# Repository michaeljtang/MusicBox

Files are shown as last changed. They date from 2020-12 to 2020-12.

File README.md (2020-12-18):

# MusicBox

Electronic music box project powered by a PocketBeagle. Full project description can be found on Hackster: https://www.hackster.io/michael-tang/programmable-music-box-1288ab

The mechanical instructions for building this project can be found in the Hackster page above. This repo contains two main folders:

### Code
This folder contains all code needed to operate the music box, as well as instructions on how to run on startup.

### PCB
This folder contains the schematic, layout, library, and more for manufacturing the PCB version of the prototype presented in the Hackster page above.

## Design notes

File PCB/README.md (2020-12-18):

# Music Box PCB

This folder includes all files necessary to manufacture a PCB for my electronic music box project. More specifically, the PCB created is intended to host all components (or connectors to components, if they are too big) necessary for the music box to run. 

In addition to a Bill-of-Materials and and PCB Schematic, this directory contains the following folders:

### /EAGLE
This folder contains the Eagle files of my PCB, and include schematic, board, as well as a library with all parts used.

### /MFG
This folder contains all the Gerber manufacturing files needed to actually manufacture my PCB

### /docs
This folder contains images of the top and bottom views of my PCB (taken from Gerber files).

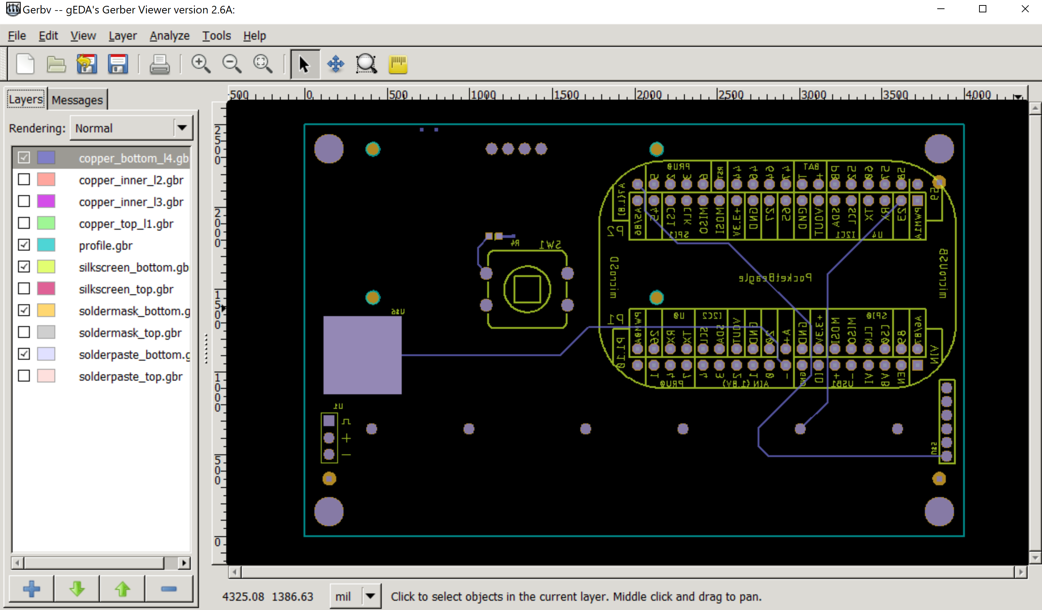
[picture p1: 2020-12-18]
PCB/docs/bottom_layer.png

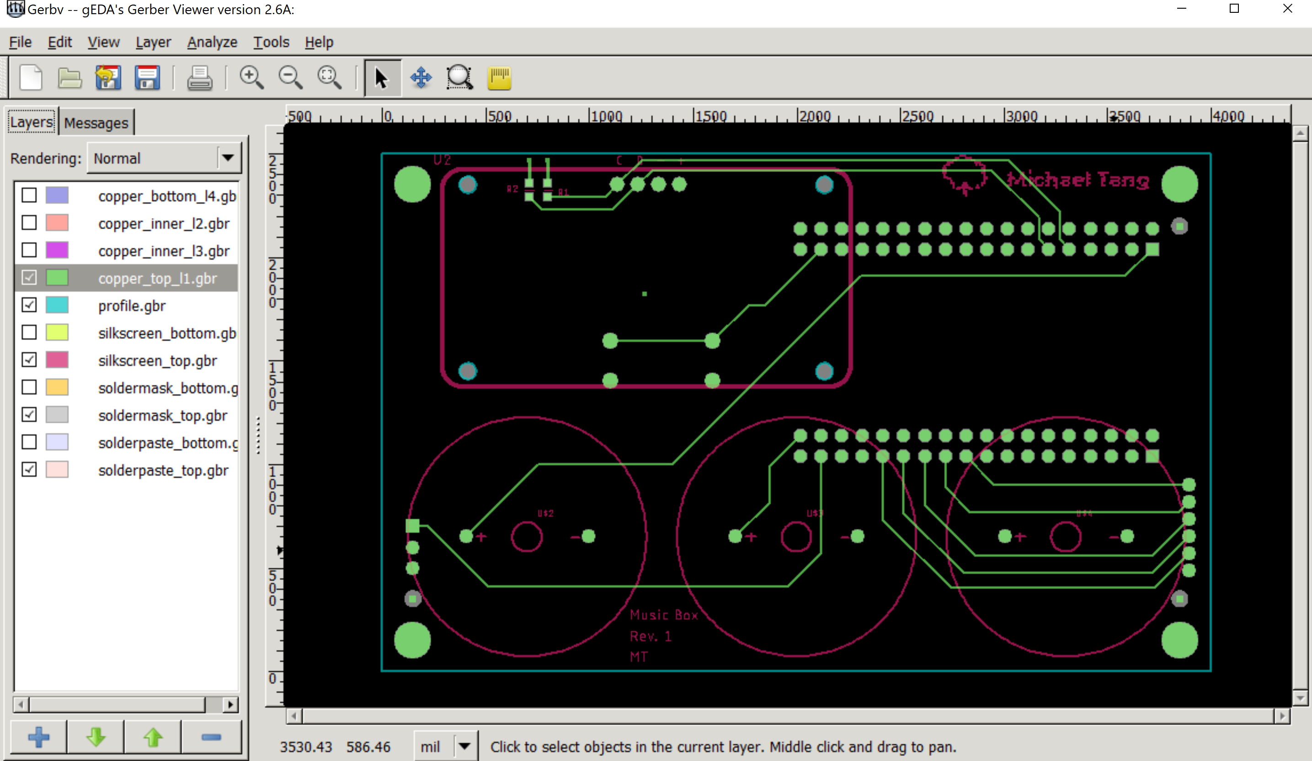
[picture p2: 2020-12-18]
PCB/docs/top_layer.png

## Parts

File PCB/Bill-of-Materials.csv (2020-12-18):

Qty | Manufacturer/MPN | Value | Device | Package | Parts/Designator | Description
1 | Adafruit HT16K33 | 0.56_HEX_BACKPACK | 0.56_HEX_BACKPACK | 0.56_HEX_BACKPACK | U2 | 0.56" LED HEX Backback - Adafruit HT16K33 -
3 | MF-RES-0603-1K | 1k | R_R0603 | R0603 | R1, R2, R4 | RESISTOR, American symbol
1 | N/A | COPPER_PLATE | COPPER_PLATE | COPPER_PLATE | U$6 | Copper plate to serve as a grounded surface
6 | N/A | FIDUCIAL | FIDUCIAL | FIDUCIAL_40MIL | FUD1, FUD2, FUD3, FUD4, FUD5, FUD6 | Fiducials to aid PCB manufacturing
1 | N/A | HEADER_PINS | HEADER_PINS | HEADER_PINS | U$5 | Standard Header Pins to act as floating analog inputs
4 | N/A | MOUNTING_HOLE | MOUNTING_HOLE | MOUNTING_HOLE | MGT1, MGT2, MGT3, MGT4 | Chassis Mounting Hole w/GND connection ability
1 | BeagleBoard | POCKETBEAGLE | POCKETBEAGLE | POCKETBEAGLE | U$1 | Microcontroller running 1GHz ARM Cortex-A8
1 | Gikfun LYSB01E38OS7K-ELECTRNCS | PUSH_BUTTON | PUSH_BUTTON | BUTTON_12.5MM | SW1 | Standard Push Button
1 | Sparkfun ROB10189 | SERVO_ROB10189 | SERVO_ROB10190 | SERVO-X1 | U1 | Continuous Rotation Servo (Micro-Size)
3 | Adafruit P1898 | SPEAKER_P1898 | SPEAKER_P1899 | SPEAKER | U$2, U$3, U$4 | PCB Mount Mini Speaker

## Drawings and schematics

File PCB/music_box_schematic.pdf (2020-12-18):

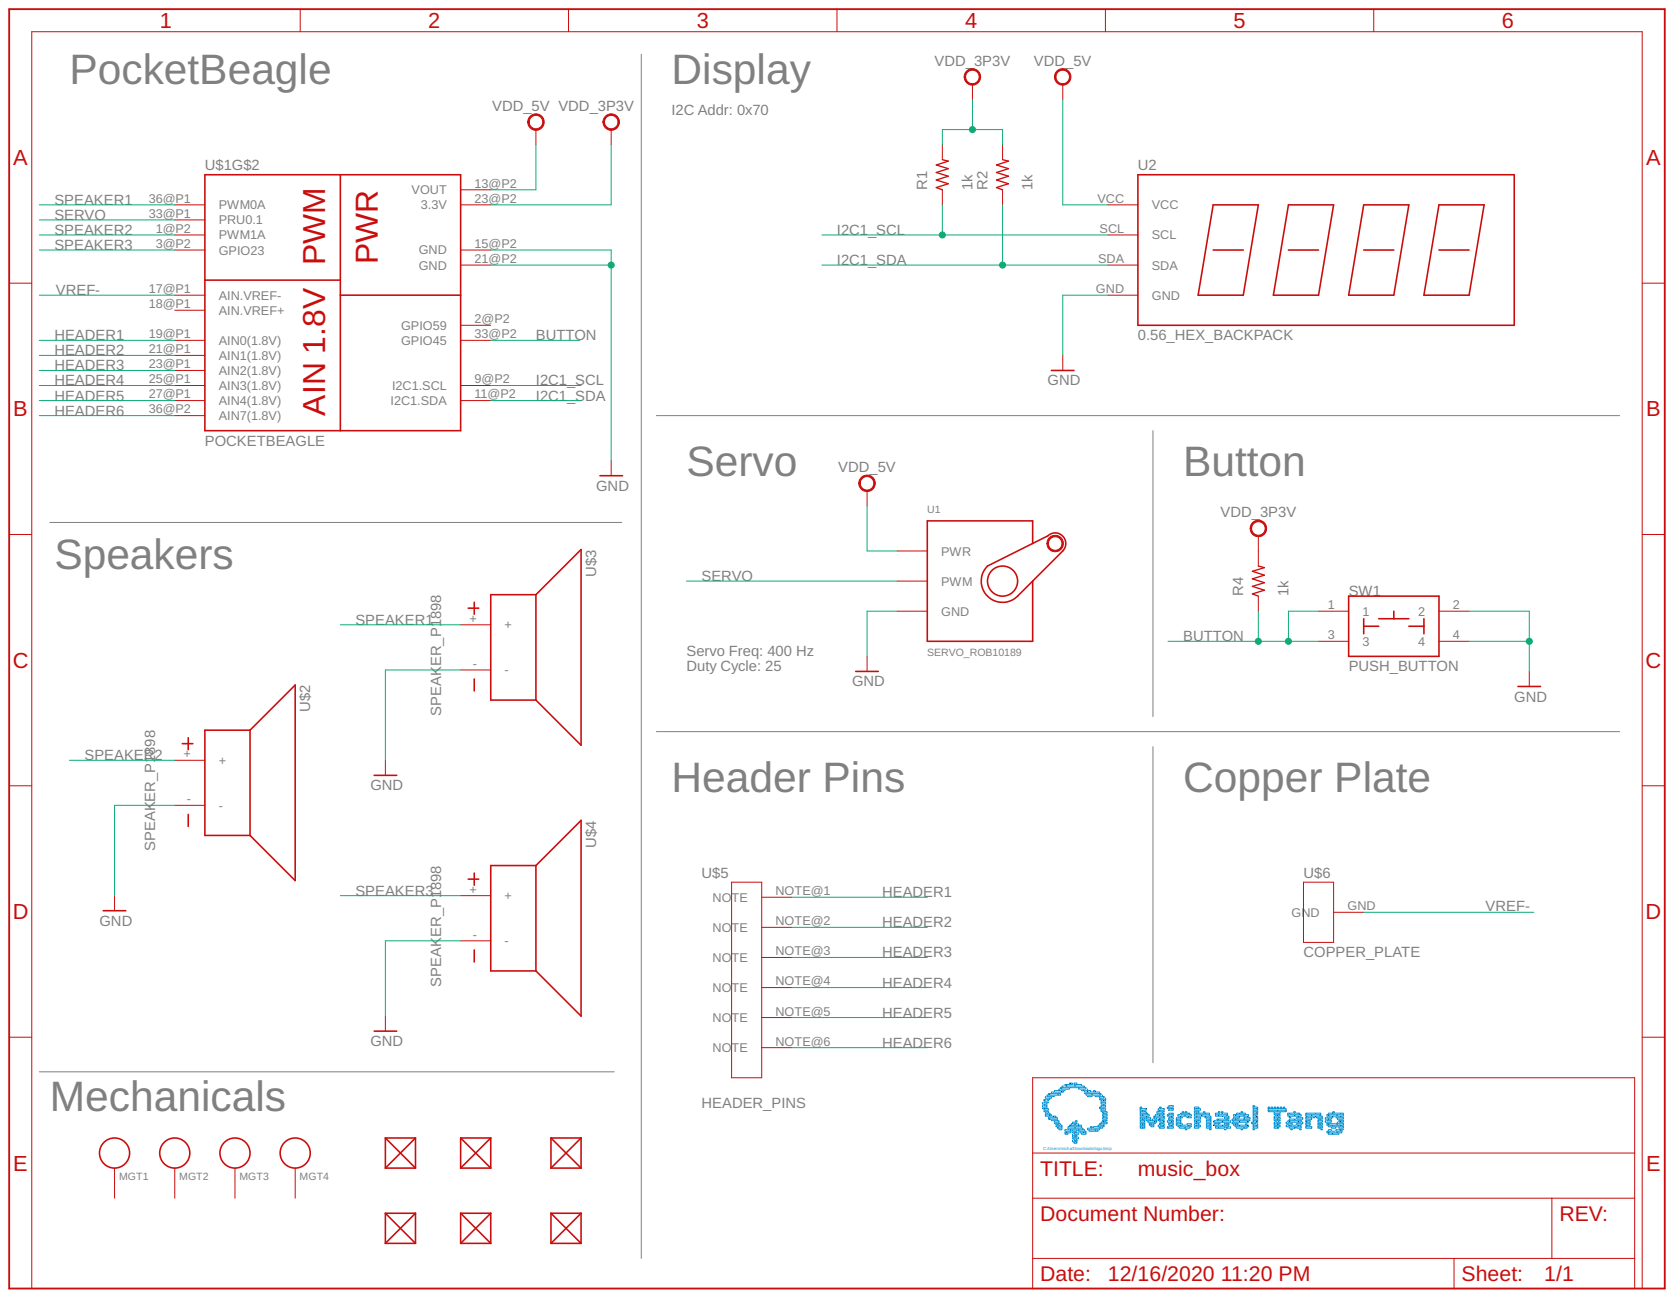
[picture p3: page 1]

HEADER1 | GPIO59 I2C1.SCL I2C1.SDA

HEADER2 | | 9@P2 I2C1_SCL

Servo Freq: 400 Hz Duty Cycle: 25

C:/Users/micha/Downloads/logo.bmp
TITLE:

Document Number: | REV:

Date: 12/16/2020 11:20 PM | Sheet: 1/1

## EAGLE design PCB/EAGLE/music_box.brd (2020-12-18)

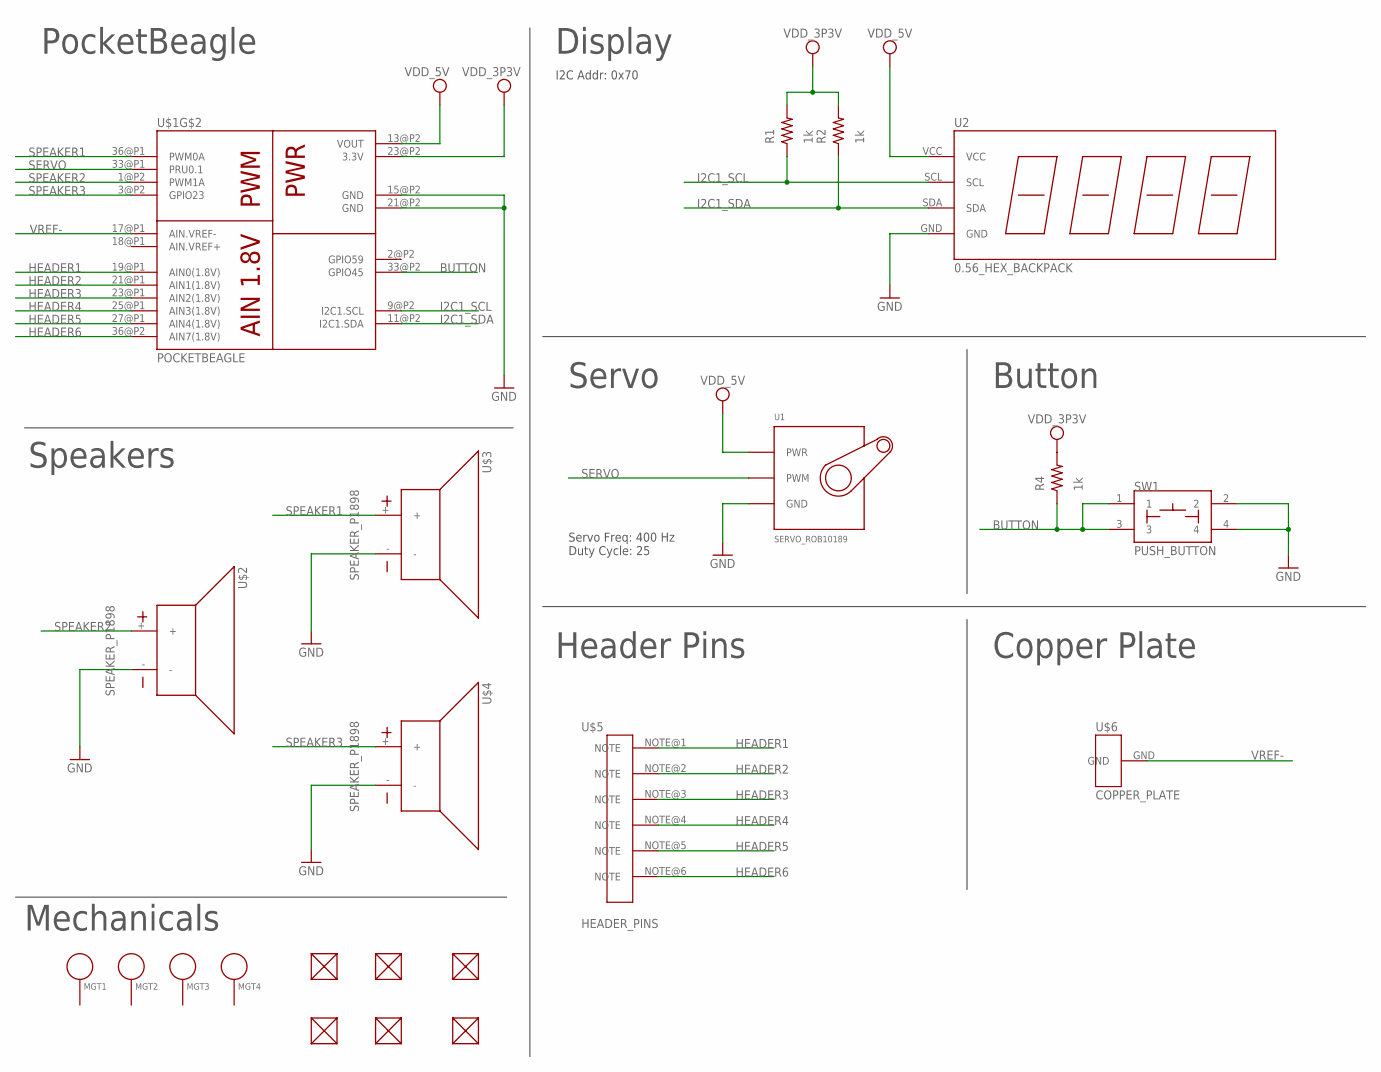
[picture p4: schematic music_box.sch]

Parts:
FUD1, FUD2, FUD3, FUD4, FUD5, FUD6: FIDUCIAL; FIDUCIAL_40MIL
MGT1, MGT2, MGT3, MGT4: MOUNTING_HOLE
R1, R2, R4: 1k; R0603
SW1: PUSH_BUTTON; BUTTON_12.5MM
U1: SERVO_ROB10189; SERVO-X1
U2: 0.56_HEX_BACKPACK
U$1: POCKETBEAGLE
U$2, U$3, U$4: SPEAKER_P1898; SPEAKER
U$5: HEADER_PINS
U$6: COPPER_PLATE

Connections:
BUTTON: R4.1, SW1.1, SW1.3, U$1.33@P2 (GPIO45)
GND: SW1.2, SW1.4, U1.GND, U2.GND, U$1.15@P2 (GND), U$1.21@P2 (GND), U$2.-, U$3.-, U$4.-
HEADER1: U$1.19@P1 (AIN0(1.8V)), U$5.NOTE@1
HEADER2: U$1.21@P1 (AIN1(1.8V)), U$5.NOTE@2
HEADER3: U$1.23@P1 (AIN2(1.8V)), U$5.NOTE@3
HEADER4: U$1.25@P1 (AIN3(1.8V)), U$5.NOTE@4
HEADER5: U$1.27@P1 (AIN4(1.8V)), U$5.NOTE@5
HEADER6: U$1.36@P2 (AIN7(1.8V)), U$5.NOTE@6
I2C1_SCL: R1.1, U2.SCL, U$1.9@P2 (I2C1.SCL)
I2C1_SDA: R2.1, U2.SDA, U$1.11@P2 (I2C1.SDA)
SERVO: U1.SIG (PWM), U$1.33@P1 (PRU0.1)
SPEAKER1: U$1.36@P1 (PWM0A), U$3.+
SPEAKER2: U$1.1@P2 (PWM1A), U$2.+
SPEAKER3: U$1.3@P2 (GPIO23), U$4.+
VDD_3P3V: R1.2, R2.2, R4.2, U$1.23@P2 (3.3V)
VDD_5V: U1.PWR, U2.VCC, U$1.13@P2 (VOUT)
VREF-: U$1.17@P1 (AIN.VREF-), U$6.GND

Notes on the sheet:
PocketBeagle
Display
Servo
Button
Header Pins
Copper Plate
Speakers
I2C Addr: 0x70
Servo Freq: 400 Hz Duty Cycle: 25
Mechanicals

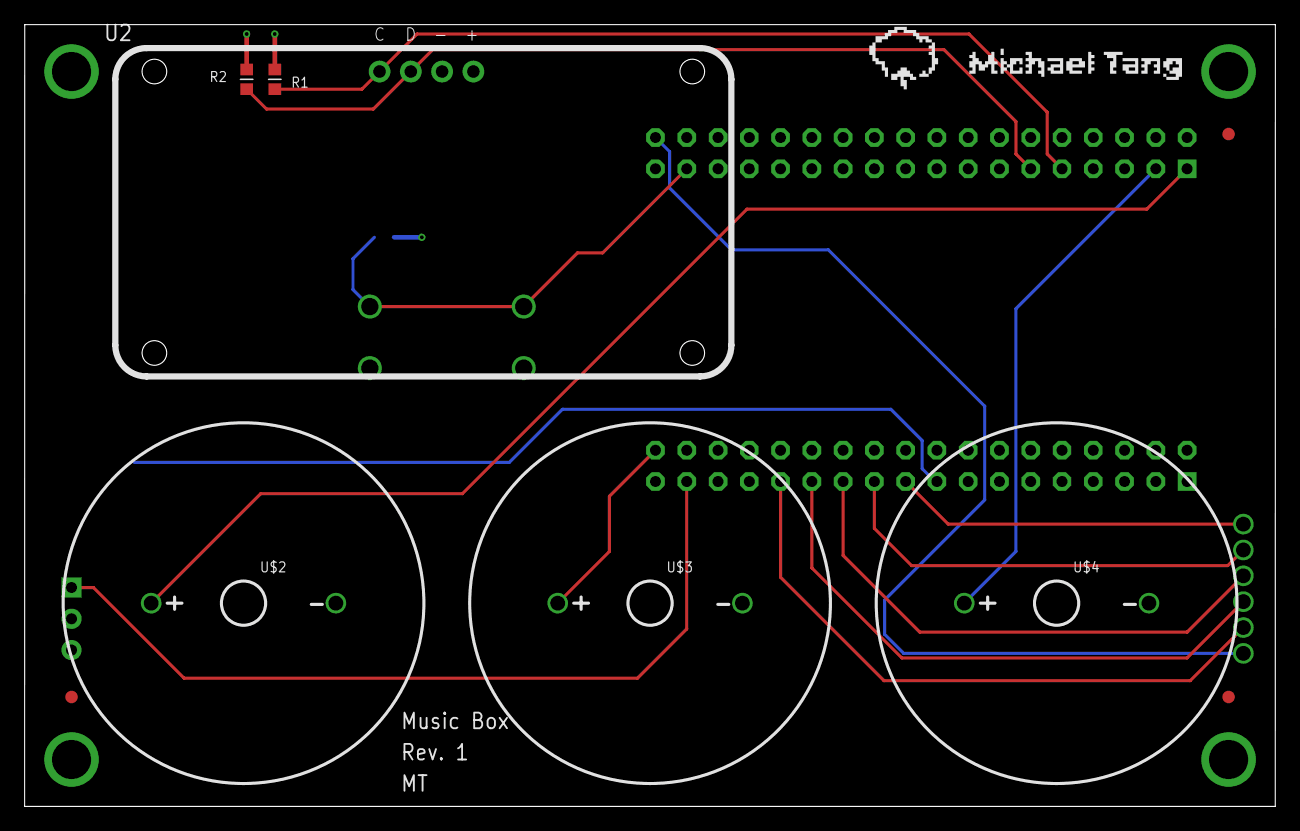
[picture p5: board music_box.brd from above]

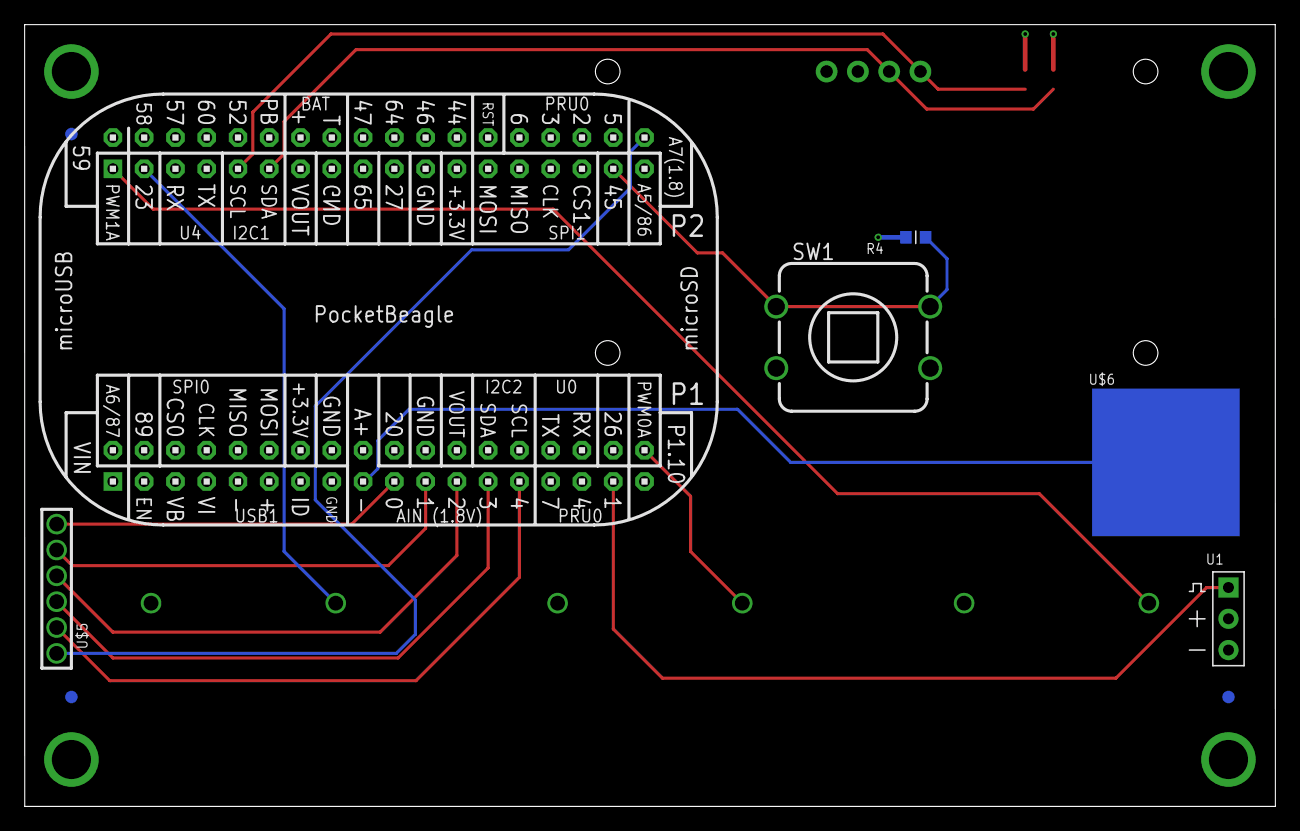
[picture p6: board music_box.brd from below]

Board: 4 copper layers, 101.6 x 63.5 mm, 22 parts (9 on the bottom side), 17 nets.

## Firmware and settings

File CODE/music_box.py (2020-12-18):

"""
--------------------------------------------------------------------------
Music Box
--------------------------------------------------------------------------
License:   
Copyright 2020 Michael Tang

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
1. Redistributions of source code must retain the above copyright notice, this 
list of conditions and the following disclaimer.

2. Redistributions in binary form must reproduce the above copyright notice, 
this list of conditions and the following disclaimer in the documentation 
and/or other materials provided with the distribution.

3. Neither the name of the copyright holder nor the names of its contributors 
may be used to endorse or promote products derived from this software without 
specific prior written permission.

THIS SOFTWARE IS PROVIDED BY THE COPYRIGHT HOLDERS AND CONTRIBUTORS "AS IS" 
AND ANY EXPRESS OR IMPLIED WARRANTIES, INCLUDING, BUT NOT LIMITED TO, THE 
IMPLIED WARRANTIES OF MERCHANTABILITY AND FITNESS FOR A PARTICULAR PURPOSE ARE 
DISCLAIMED. IN NO EVENT SHALL THE COPYRIGHT HOLDER OR CONTRIBUTORS BE LIABLE 
FOR ANY DIRECT, INDIRECT, INCIDENTAL, SPECIAL, EXEMPLARY, OR CONSEQUENTIAL 
DAMAGES (INCLUDING, BUT NOT LIMITED TO, PROCUREMENT OF SUBSTITUTE GOODS OR 
SERVICES; LOSS OF USE, DATA, OR PROFITS; OR BUSINESS INTERRUPTION) HOWEVER 
CAUSED AND ON ANY THEORY OF LIABILITY, WHETHER IN CONTRACT, STRICT LIABILITY, 
OR TORT (INCLUDING NEGLIGENCE OR OTHERWISE) ARISING IN ANY WAY OUT OF THE USE 
OF THIS SOFTWARE, EVEN IF ADVISED OF THE POSSIBILITY OF SUCH DAMAGE.
--------------------------------------------------------------------------
Software for running a programmable music box.

Main Components used:
  - HT16K33 Display
  - 1 push button
  - 3 speakers
  - 1 Micro-size continuous rotation servo
  - Copper plate

Uses:
  - HT16K33 display library developed by Erik Welsh
  - motor.py (in folder) for running thread for continuous rotation servo
  - speaker.py (in folder) for running thread for speaker

"""
from speaker import *
from motor import *
import Adafruit_BBIO.GPIO as GPIO
import Adafruit_BBIO.ADC as ADC
import threading

import ht16k33 as HT16K33

# ------------------------------------------------------------------------
# Constants
# ------------------------------------------------------------------------
# threshold sets what voltages our pins need to hit for a sound to be played
THRESHOLD = 500

# ------------------------------------------------------------------------
# Global variables
# ------------------------------------------------------------------------
# determines whether our music box is on or off; is controlled by the Button thread, and affects the MusicBox class
music_box_on = False

class MusicBox():
    # pins corresponding to each speaker, and a list for storing each speaker's threads
    speaker_0 = None
    speaker_1 = None
    speaker_2 = None
    speaker_threads = []
    
    # dict to store pins corresponding to each note
    note_pins = {}
    
    # object representing 7-segment display
    display = None
    
    # object representing motor
    motor = None
    motor_thread = None
    
    def __init__(self, speaker_0="P1_36", speaker_1="P2_3", speaker_2="P2_1", C="P1_27", D="P1_19", E="P1_21", F="P1_23", G="P1_25", A="P2_35", B="P2_36", i2c_bus=1, i2c_address=0x70, motor="P1_33"):
        """
        Intializes variables to appropriate pins
        """
        # initialize speaker pins
        self.speaker_0 = speaker_0
        self.speaker_1 = speaker_1
        self.speaker_2 = speaker_2

        # initialize note pins
        #self.note_pins['A'] = A
        self.note_pins['B'] = B
        self.note_pins['C'] = C
        self.note_pins['D'] = D
        self.note_pins['E'] = E
        self.note_pins['F'] = F
        self.note_pins['G'] = G
        
        # initialize 7-segment display
        self.display = HT16K33.HT16K33(i2c_bus, i2c_address)
        
        # Initialize motor pin
        self.motor = motor
        
        # setup all of the pins
        self._setup()
    
    def _setup(self):
        """
        Sets up device for initial use
        """
        # Initialize Display
        self.set_display_off()
        
        # Initialize Analog Inputs
        ADC.setup()
        
        # Initialize Motor
        self.motor_thread = RunMotor(self.motor)       
        self.motor_thread.start()
        
        # Setup speaker threads into a dictionary
        self.speaker_threads = [PlayNote(self.speaker_0), PlayNote(self.speaker_1), PlayNote(self.speaker_2)]
        for thread in self.speaker_threads:
            thread.start()
            
    
    def run(self):
        """
        Runs music box
        """
        while(True):
            # only start running music box if button has been pressed to on
            if music_box_on:
                self.turn_on()
                
                # check each input pin to see if certain notes are being played (need 4 consecutive values to be high)
                on = []
                for note in self.note_pins.keys():
                    if self.check_threshold(self.note_pins[note]):
                        on.append(note)
                        
                # only take first 3 notes detected (as we have 3 speakers)
                for i, note in enumerate(on[:3]):
                    self.speaker_threads[i].add_note(note)
            
            # if button is pressed to off, then turn off the music box
            else:
                self.turn_off()
    
    def check_threshold(self, pin):
        """
        Checks if an input has hit under threshold voltage (ie. it is toggled on when
        voltage is low enough
        
        Input: analog input pin to check
        Output: true if input has hit threshold voltage
        """
        measured = []
        # read 3 times to average out noise in pin reading
        for i in range(3):
            measured.append(ADC.read_raw(pin))
        return max(measured) <= THRESHOLD
        
    def set_display_on(self):
        """
        Set display to "on"
        """
        self.display.set_digit_raw(0, 0x6F)        # "G"
        self.display.set_digit_raw(1, 0x3F)        # "O"
        self.display.set_digit_raw(2, 0x00)        # " "
        self.display.set_digit_raw(3, 0x00)        # " "
        
    def set_display_off(self):
        """
        Set display to "off"
        """
        self.display.set_digit_raw(0, 0x3F)        # "O"
        self.display.set_digit_raw(1, 0x71)        # "F"
        self.display.set_digit_raw(2, 0x71)        # "F"
        self.display.set_digit_raw(3, 0x00)        # " "
        
    def turn_off(self):
        """
        Sets music box to off mode
        """
        # set display to off
        self.set_display_off()
        
        # stop motor
        self.motor_thread.pause()
        
    def turn_on(self):
        """
        Sets music box to on mode
        """
        # set display to on
        self.set_display_on()
        
        # start motor
        self.motor_thread.unpause()
        
    def cleanup(self):
        """
        Clean up threads
        """
        # Stop speaker threads
        for speaker_thread in self.speaker_threads:
            speaker_thread.end()
        
        # Stop motor thread
        self.motor_thread.end()
        
        # Clean up threads
        main_thread = threading.currentThread()
        for thread in threading.enumerate():
            if thread is not main_thread:
                thread.join()
        
        # Set Display to show program is complete
        self.display.set_digit(0, 13)        # "D"
        self.display.set_digit(1, 14)        # "E"
        self.display.set_digit(2, 10)        # "A"
        self.display.set_digit(3, 13)        # "D"
        
class BoxButton(threading.Thread):
    button = None
    # False corresponds to off, True corresponds to on
    prev_state = False
    stop = False
    
    def __init__(self, button="P2_2"):
        """
        Initialize thread as well as class fields to appropriate pins
        """
        threading.Thread.__init__(self)
        self.button = button
        
        # Initialize button
        GPIO.setup(self.button, GPIO.IN)
        
    def run(self):
        """
        Runs button by having it continuous checking for it to turn on/off
        """
        # make sure we can set global variable
        global music_box_on
        
        while not self.stop:
            # check if button is pressed
            if GPIO.input(self.button) == 0:
                # if prev_state was false, then it was just turned on
                if self.prev_state == False:
                    # previous state now becomes on
                    self.prev_state = True
                    music_box_on = True
                    
                # if prev_state was true, then it was fjust turned off
                else:
                    self.prev_state = False
                    music_box_on = False
                    
                # pause for a bit so it doesn't read a single click as multiple
                time.sleep(0.2)
    
    def end(self):
        """
        Stops thread
        """
        self.stop = True

if __name__ == '__main__':
    # Initialize all objects necessary to run music box
    box = MusicBox()
    button = BoxButton()
    button.start()
    
    try:
        box.run()
    # program terminates upon KeyBoard Interrupt
    except KeyboardInterrupt:
        # Initiate cleanup 
        box.cleanup()
        button.end()
        
        # Stop threads
        main_thread = threading.currentThread()
        for thread in threading.enumerate():
            if thread is not main_thread:
                thread.join()

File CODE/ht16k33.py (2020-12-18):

# -*- coding: utf-8 -*-
"""
--------------------------------------------------------------------------
HT16K33 I2C Library
--------------------------------------------------------------------------
License:   
Copyright 2018 Erik Welsh

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
1. Redistributions of source code must retain the above copyright notice, this 
list of conditions and the following disclaimer.

2. Redistributions in binary form must reproduce the above copyright notice, 
this list of conditions and the following disclaimer in the documentation 
and/or other materials provided with the distribution.

3. Neither the name of the copyright holder nor the names of its contributors 
may be used to endorse or promote products derived from this software without 
specific prior written permission.

THIS SOFTWARE IS PROVIDED BY THE COPYRIGHT HOLDERS AND CONTRIBUTORS "AS IS" 
AND ANY EXPRESS OR IMPLIED WARRANTIES, INCLUDING, BUT NOT LIMITED TO, THE 
IMPLIED WARRANTIES OF MERCHANTABILITY AND FITNESS FOR A PARTICULAR PURPOSE ARE 
DISCLAIMED. IN NO EVENT SHALL THE COPYRIGHT HOLDER OR CONTRIBUTORS BE LIABLE 
FOR ANY DIRECT, INDIRECT, INCIDENTAL, SPECIAL, EXEMPLARY, OR CONSEQUENTIAL 
DAMAGES (INCLUDING, BUT NOT LIMITED TO, PROCUREMENT OF SUBSTITUTE GOODS OR 
SERVICES; LOSS OF USE, DATA, OR PROFITS; OR BUSINESS INTERRUPTION) HOWEVER 
CAUSED AND ON ANY THEORY OF LIABILITY, WHETHER IN CONTRACT, STRICT LIABILITY, 
OR TORT (INCLUDING NEGLIGENCE OR OTHERWISE) ARISING IN ANY WAY OUT OF THE USE 
OF THIS SOFTWARE, EVEN IF ADVISED OF THE POSSIBILITY OF SUCH DAMAGE.
--------------------------------------------------------------------------
Software API:

  HT16K33(bus, address=0x70)
    - Provide i2c bus that dispaly is on
    - Provide i2c address for the display
    
    clear()
      - Sets value of display to "0000"
    
    update(value)
      - Update the value on the display.  Value must be between 0 and 9999. 
      
  
--------------------------------------------------------------------------
Background Information: 
 
  * Using seven-segment digit LED display for Adafruit's HT16K33 I2C backpack:
    * http://adafruit.com/products/878
    * https://learn.adafruit.com/assets/36420
    * https://cdn-shop.adafruit.com/datasheets/ht16K33v110.pdf
    
    * Base code (adapted below):
        * https://github.com/emcconville/HT16K33/blob/master/FourDigit.py
        * https://github.com/emcconville/HT16K33/blob/master/_HT16K33.py
        * https://github.com/adafruit/Adafruit_Python_LED_Backpack/blob/master/Adafruit_LED_Backpack/HT16K33.py
        * https://github.com/adafruit/Adafruit_Python_LED_Backpack/blob/master/Adafruit_LED_Backpack/SevenSegment.py
        * https://github.com/adafruit/Adafruit_Python_LED_Backpack/blob/master/examples/sevensegment_test.py

"""
import os


# ------------------------------------------------------------------------
# Constants
# ------------------------------------------------------------------------
HEX_DIGITS                  = [0x3f, 0x06, 0x5b, 0x4f,    # 0, 1, 2, 3
                               0x66, 0x6d, 0x7d, 0x07,    # 4, 5, 6, 7
                               0x7f, 0x6f, 0x77, 0x7c,    # 8, 9, A, b
                               0x39, 0x5e, 0x79, 0x71]    # C, d, E, F

CLEAR_DIGIT                 = 0x7F
POINT_VALUE                 = 0x80

DIGIT_ADDR                  = [0x00, 0x02, 0x06, 0x08]
COLON_ADDR                  = 0x04
                      
HT16K33_BLINK_CMD           = 0x80
HT16K33_BLINK_DISPLAYON     = 0x01
HT16K33_BLINK_OFF           = 0x00
HT16K33_BLINK_2HZ           = 0x02
HT16K33_BLINK_1HZ           = 0x04
HT16K33_BLINK_HALFHZ        = 0x06

HT16K33_SYSTEM_SETUP        = 0x20
HT16K33_OSCILLATOR          = 0x01

HT16K33_BRIGHTNESS_CMD      = 0xE0
HT16K33_BRIGHTNESS_HIGHEST  = 0x0F
HT16K33_BRIGHTNESS_DARKEST  = 0x00


# ------------------------------------------------------------------------
# Functions / Classes
# ------------------------------------------------------------------------
class HT16K33():
    """ Class to manage a HT16K33 I2C display """
    bus     = None
    address = None
    command = None
    
    def __init__(self, bus, address=0x70):
        """ Initialize variables and set up display """
        self.bus     = bus
        self.address = address
        self.command = "/usr/sbin/i2cset -y {0} {1}".format(bus, address)
        
        self.setup(blink=HT16K33_BLINK_OFF, brightness=HT16K33_BRIGHTNESS_HIGHEST)
    
    # End def
    
    def setup(self, blink, brightness):
        """Initialize the display itself"""
        # i2cset -y 1 0x70 0x21
        os.system("{0} {1}".format(self.command, (HT16K33_SYSTEM_SETUP | HT16K33_OSCILLATOR)))
        # i2cset -y 1 0x70 0x81
        os.system("{0} {1}".format(self.command, (HT16K33_BLINK_CMD | blink | HT16K33_BLINK_DISPLAYON)))
        # i2cset -y 1 0x70 0xEF
        os.system("{0} {1}".format(self.command, (HT16K33_BRIGHTNESS_CMD | brightness)))

    # End def    


    def encode(self, data, double_point=False):
        """Encode data to TM1637 format.
        
        This function will convert the data from decimal to the TM1637 data fromt
        
        :param value: Value must be between 0 and 15
        
        Will throw a ValueError if number is not between 0 and 15.
        """
        ret_val = 0
        
        try:
            if (data != CLEAR_DIGIT):
                if double_point:
                    ret_val = HEX_DIGITS[data] + POINT_VALUE
                else:
                    ret_val = HEX_DIGITS[data]
        except:
            raise ValueError("Digit value must be between 0 and 15.")
    
        return ret_val

    # End def


    def set_digit(self, digit_number, data, double_point=False):
        """Update the given digit of the display."""
        os.system("{0} {1} {2}".format(self.command, DIGIT_ADDR[digit_number], self.encode(data, double_point)))    

    # End def


    def set_digit_raw(self, digit_number, data, double_point=False):
        """Update the given digit of the display using raw data value"""
        os.system("{0} {1} {2}".format(self.command, DIGIT_ADDR[digit_number], data))    

    # End def


    def set_colon(self, enable):
        """Set the colon on the display."""
        if enable:
            os.system("{0} {1} {2}".format(self.command, COLON_ADDR, 0x02))
        else:
            os.system("{0} {1} {2}".format(self.command, COLON_ADDR, 0x00))

    # End def        


    def clear(self):
        """Clear the display to read '0000'"""
        self.set_colon(False)

        self.set_digit(3, 0)
        self.set_digit(2, 0)
        self.set_digit(1, 0)
        self.set_digit(0, 0)

    # End def
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
